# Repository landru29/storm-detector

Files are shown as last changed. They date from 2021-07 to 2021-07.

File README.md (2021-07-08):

# Lightning detector

## Libraries

- OneWire
- SparkFun AS3935
- Adafruit SSD1306
- Piezzo (optional)

## Parts

- 1x Oled 128x64
- 1x AS3935
- 1x Arduino nano Atmega 328P
- 1x Rotary encoder
- 2x Capacitor 0.1µF

## Connections

### Screen OLED

- OLED GND <-> Arduino GND
- OLED VDD <-> Arduino 5V
- OLED SCK <-> Arduino A5
- OLED SDA <-> Arduino A4

### AS3935 Detector

- AS3935 VDD  <-> Arduino 5V
- AS3935 GND  <-> Arduino GND
- AS3935 SCL  <-> ARDUINO D13
- AS3935 MOSI <-> ARDUINO D11
- AS3935 MISO <-> ARDUINO D12
- AS3935 CS   <-> ARDUINO D10
- AS3935 SI   <-> Arduino GND (force spi)
- AS3935 IRQ  <-> Arduino D3
- AS3935 EN_V <-> Arduino 5V
- AS3935 A0   <-> Arduino 5V
- AS3935 A1   <-> Arduino 5V

### Rotary Encoder

``` text
    -----------
 A--|         |
    | Rotary  |--S1
 C--|         |
    | Encoder |--S2
 B--|         |
    -----------
```

- Encoder S1 <-> Arduino GND
- Encoder S2 <-> Arduino D4
- Encoder A  <-> Arduino D2
- Encoder B  <-> Arduino D5
- Encoder C  <-> Arduino GND

### Capacitors

- Cap1 + <-> Arduino D2
- Cap1 - <-> Arduino GND
- Cap2 + <-> Arduino D5
- Cap2 - <-> Arduino GND

### Piezzo (optional)

- Piezzo <-> Arduino D7
- Piezzo <-> Arduino GND

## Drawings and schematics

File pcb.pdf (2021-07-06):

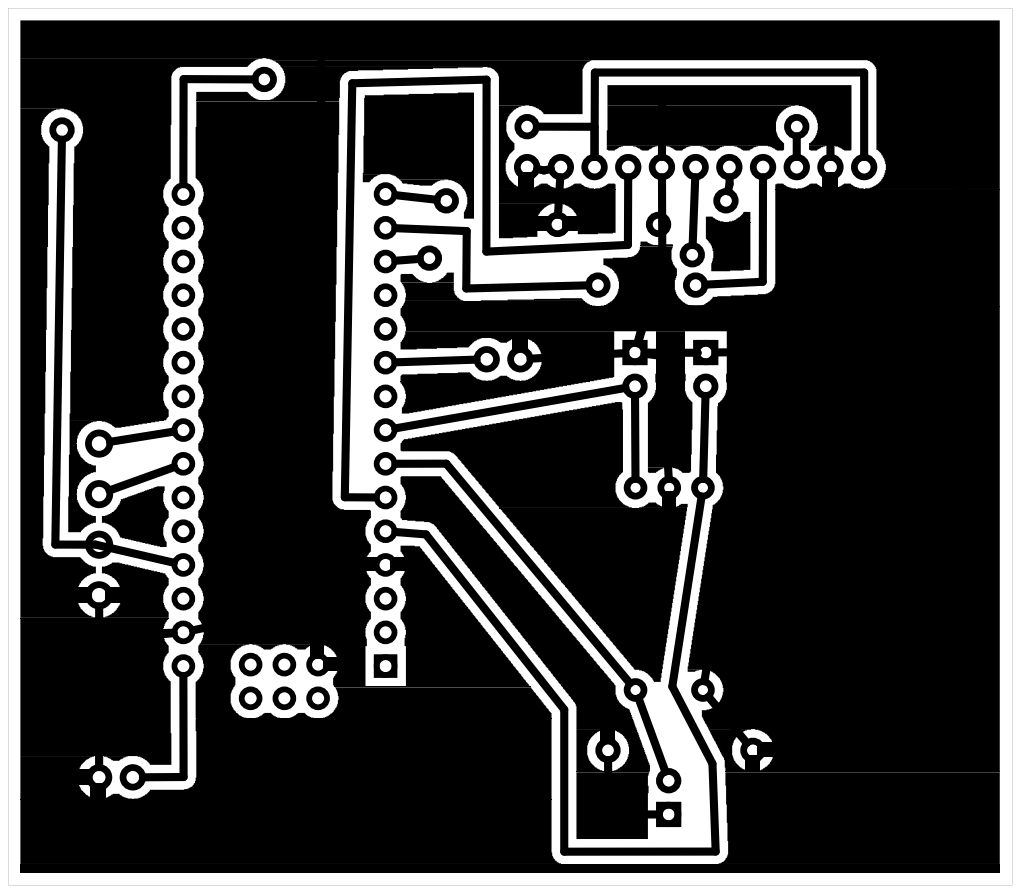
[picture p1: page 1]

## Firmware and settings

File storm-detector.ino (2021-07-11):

#include <Wire.h>
#include <SPI.h>
#include <EEPROM.h>
#include "SparkFun_AS3935.h"
#include "Adafruit_SSD1306.h"
#include "splash.h"

//#define DEBUG

// Button
#define BUTTON 4
#define ROTARY_INTERRUPT 2
#define STEP   5

// Piezzo
#define PIEZZO 7

//SPI chip select pin
#define CHIP_SELECT 10

// Detector mode
#define INDOOR 0x12 
#define OUTDOOR 0xE

// Type of signal
#define LIGHTNING_INT 0x08
#define DISTURBER_INT 0x04
#define NOISE_INT     0x01

#define PAGE_MAIN             1
#define PAGE_MODE             2
#define PAGE_NOISE            3
#define PAGE_WATCHDOG         4
#define PAGE_REJECTIONS       5
#define PAGE_LIGHTNING        6
#define PAGE_MASK_DISTURBERS  7
#define LAST_PAGE             7

// Interrupt pin for lightning detection
#define LIGHTNING_INTERRUPT_PIN 3

// OLED constants
#define SCREEN_WIDTH   128   // OLED display width, in pixels
#define SCREEN_HEIGHT  64    // OLED display height, in pixels
#define OLED_RESET     4     // Reset pin # (or -1 if sharing Arduino reset pin)
#define SCREEN_ADDRESS 0x3C  // See datasheet for Address; 0x3D for 128x64, 0x3C for 128x32

SparkFun_AS3935 lightning;
Adafruit_SSD1306 display(SCREEN_WIDTH, SCREEN_HEIGHT, &Wire, OLED_RESET);

// Counters
unsigned int strikeCount    = 0;
unsigned int noiseCount     = 0;
unsigned int disturberCount = 0;
unsigned int otherCount     = 0;

// Detector configuration
bool modeOut              = true;
bool maskDisturbers       = false;
byte noise                = 2; // Value between 1-7
byte watchDogVal          = 2; // Value between 1-10
byte spike                = 2; // Value between 1-11
byte lightningThresh[4]   = {1, 5, 9, 16}; // Value in [1, 5, 9, 16]
byte lightningThreshIndex = 0;
 

// This variable holds the number representing the lightning or non-lightning
// event issued by the lightning detector.
byte intVal      = 0;
byte distance;
long lightEnergy = 0;

byte page = 1;

bool buttonUp = true;

void setup() {
    loadConfig();
    
    Wire.begin();

    pinMode(BUTTON, INPUT_PULLUP);
    pinMode(ROTARY_INTERRUPT, INPUT_PULLUP);
    pinMode(STEP, INPUT_PULLUP);
    pinMode(PIEZZO, OUTPUT);

    // When lightning is detected the interrupt pin goes HIGH.
    pinMode(LIGHTNING_INTERRUPT_PIN, INPUT);

    #ifdef DEBUG
    Serial.begin(115200);
    #endif // DEBUG

    digitalWrite(PIEZZO, HIGH);

    // SSD1306_SWITCHCAPVCC = generate display voltage from 3.3V internally
    if (!display.begin(SSD1306_SWITCHCAPVCC, SCREEN_ADDRESS)) {
        #ifdef DEBUG
        Serial.println("SSD1306 allocation failed, freezing!");
        #endif // DEBUG
        while (1);
    }

    display.clearDisplay();
    display.drawBitmap(
        (SCREEN_WIDTH - splash_width) / 2,
        (SCREEN_HEIGHT - splash_height) / 2,
        splash_data,
        splash_width,
        splash_height,
        1
    );

    digitalWrite(PIEZZO, LOW);

    // Show initial display buffer contents on the screen --
    // the library initializes this with an Adafruit splash screen.
    display.display();

    delay(2000); // Pause for 2 seconds

    digitalWrite(PIEZZO, HIGH);

    display.setTextSize(1);              // Normal 1:1 pixel scale
    display.setTextColor(SSD1306_WHITE); // Draw white text
    display.cp437(true);                 // Use full 256 char 'Code Page 437' font

    display.writeFillRect(0, 0, SCREEN_WIDTH, 16, 0);
    display.setCursor(0, 0);
    display.println(" LIGHTNINGS - starting ");
    display.display();

    digitalWrite(PIEZZO, LOW);


    #ifdef DEBUG
    Serial.println("AS3935 Franklin Lightning Detector");
    #endif // DEBUG

    SPI.begin(); 

    if (!lightning.beginSPI(CHIP_SELECT)) {
        #ifdef DEBUG
        Serial.println("Lightning Detector did not start up, freezing!");
        #endif // DEBUG
        display.writeFillRect(0, 0, SCREEN_WIDTH, 16, 0);
        display.setCursor(0, 0);
        display.println(" LIGHTNINGS - ERROR ");
        display.writeFillRect(0, 16, SCREEN_WIDTH, SCREEN_HEIGHT-16, 0);
        display.setCursor(0, 16);
        display.println("Detector not found");
        display.display();
        while (1);
    }

    #ifdef DEBUG
    Serial.println("Lightning Detector Ready!");
    #endif // DEBUG
    display.writeFillRect(0, 0, SCREEN_WIDTH, 16, 0);
    display.setCursor(0, 0);
    display.println(" LIGHTNINGS - AS3935 ");
    display.display();

    // The lightning detector defaults to an indoor setting at
    // the cost of less sensitivity, if you plan on using this outdoors
    // uncomment the following line:
    lightning.setIndoorOutdoor(modeOut ? OUTDOOR: INDOOR);

    // Noise floor setting from 1-7, one being the lowest. Default setting is
    // 2. If you need to check the setting, the corresponding function for
    // reading the function follows. 
    lightning.setNoiseLevel(noise);

    // Watchdog threshold setting can be from 1-10, one being the lowest. Default setting is
    // 2. If you need to check the setting, the corresponding function for
    // reading the function follows.    
    lightning.watchdogThreshold(watchDogVal);

    // Spike Rejection setting from 1-11, one being the lowest. Default setting is
    // 2. If you need to check the setting, the corresponding function for
    // reading the function follows.    
    // The shape of the spike is analyzed during the chip's
    // validation routine. You can round this spike at the cost of sensitivity to
    // distant events. 
    lightning.spikeRejection(spike); 

    // This setting will change when the lightning detector issues an interrupt.
    // For example you will only get an interrupt after five lightning strikes
    // instead of one. Default is one, and it takes settings of 1, 5, 9 and 16.   
    // Followed by its corresponding read function. Default is zero. 
    lightning.lightningThreshold(lightningThresh[lightningThreshIndex]); 

    // "Disturbers" are events that are false lightning events. If you find
    // yourself seeing a lot of disturbers you can have the chip not report those
    // events on the interrupt lines. 
    lightning.maskDisturber(maskDisturbers); 

    // When signal is raising on interrupt pin (when a lighting occurs),
    // execute process
    attachInterrupt(digitalPinToInterrupt(LIGHTNING_INTERRUPT_PIN), process, RISING);

    // Manage the rotary encoder
    attachInterrupt(digitalPinToInterrupt(ROTARY_INTERRUPT), rotation, FALLING);

    page = 0;

    #ifdef DEBUG
        int enviVal = lightning.readIndoorOutdoor();
        Serial.print("Are we set for indoor or outdoor: ");  
        if( enviVal == INDOOR ) {
            Serial.println("Indoor.");  
        } else if( enviVal == OUTDOOR ) {
            Serial.println("Outdoor.");  
        } else { 
            Serial.println(enviVal, BIN);
        }
        
        int noiseVal = lightning.readNoiseLevel();
        Serial.print("Noise Level is set at: ");
        Serial.println(noiseVal);

        int watchVal = lightning.readWatchdogThreshold();
        Serial.print("Watchdog Threshold is set to: ");
        Serial.println(watchVal);

        int spikeVal = lightning.readSpikeRejection();
        Serial.print("Spike Rejection is set to: ");
        Serial.println(spikeVal);

        uint8_t lightVal = lightning.readLightningThreshold();
        Serial.print("The number of strikes before interrupt is triggerd: "); 
        Serial.println(lightVal); 

        Serial.print("Are disturbers being masked: ");
        int maskVal = lightning.readMaskDisturber();
        if (maskVal == 1) {
            Serial.println("YES"); 
        } else if (maskVal == 0) {
            Serial.println("NO"); 
        }

    #endif // DEBUG
}

void loop() {
    /*if (digitalRead(LIGHTNING_INTERRUPT_PIN) == HIGH) {
        process();
    }*/

    if ((digitalRead(BUTTON) == HIGH) && buttonUp) {
        buttonUp = false;
        page++;
        if (page>LAST_PAGE) {
            saveConfig();
            page=1;
        }
    }

    if (digitalRead(BUTTON) == LOW) {
        buttonUp = true;
    }

    switch(page) {
    default:
        display.clearDisplay();
        display.setCursor(0, 0);
        display.println("LIGHTNINGS - AS3935 ");
        display.setCursor(0, 16);
        display.print("Strike: ");
        display.println(strikeCount);
        display.setCursor(0, 24);
        display.print("Distance: ");
        display.print(distance);
        display.println("km");
        display.setCursor(0, 32);
        display.print("Energy: ");
        display.println(lightEnergy);

        display.setCursor(0, 48);
        display.print("Noise: ");
        display.println(noiseCount);

        display.setCursor(0, 56);
        display.print("Disturb: ");
        display.println(disturberCount);

        // display.setCursor(0, 56);
        // display.print("Other: ");
        // display.print(otherCount);
        // display.print(" / ");
        // display.print(intVal);
        display.display();
        break;

    case PAGE_MODE:
        display.clearDisplay();
        display.setCursor(0, 0);
        display.println("LIGHTNINGS - MODE ");
        display.setCursor(0, 16);
        display.print("Mode: ");
        if (modeOut) {
            display.println("Outdoor");
        } else {
            display.println("Indoor");
        }
        display.display();
        break;

    case PAGE_NOISE:
        display.clearDisplay();
        display.setCursor(0, 0);
        display.println("LIGHTNINGS - NOISE ");
        display.setCursor(0, 16);
        display.print("Noise: ");
        display.println(noise);
        display.display();
        break;

    case PAGE_WATCHDOG:
        display.clearDisplay();
        display.setCursor(0, 0);
        display.println("LIGHTNINGS - WATCHDOG ");
        display.setCursor(0, 16);
        display.print("Watchdog: ");
        display.println(watchDogVal);
        display.display();
        break;

    case PAGE_REJECTIONS:
        display.clearDisplay();
        display.setCursor(0, 0);
        display.println("LIGHTNINGS - REJECT ");
        display.setCursor(0, 16);
        display.print("Spike reject: ");
        display.println(spike);
        display.display();
        break;

    case PAGE_LIGHTNING:
        display.clearDisplay();
        display.setCursor(0, 0);
        display.println("LIGHTNINGS - THRESHOL ");
        display.setCursor(0, 16);
        display.print("Threshold: ");
        display.println(lightningThresh[lightningThreshIndex]);
        display.display();
        break;
    
    case PAGE_MASK_DISTURBERS:
        display.clearDisplay();
        display.setCursor(0, 0);
        display.println("LIGHTNINGS - MASK ");
        display.setCursor(0, 16);
        display.print("Mask disturb: ");
        if (maskDisturbers) {
            display.println("Yes");
        } else {
            display.println("No");
        }
        display.display();
        break;
    }

    delay(100);
}

void rotation() {
    noInterrupts();
    bool dir = (digitalRead(STEP) == LOW);

    switch(page) {
    case PAGE_MODE:
        modeOut = !modeOut;
        lightning.setIndoorOutdoor(modeOut ? OUTDOOR: INDOOR);
        break;

    case PAGE_NOISE:
        if (dir) {
            noise++;
            if (noise>7) {
                noise=1;
            }
        } else {
            noise--;
            if (noise<1) {
                noise = 7;
            }
        }
        lightning.setNoiseLevel(noise);
        break;

    case PAGE_WATCHDOG:
        if (dir) {
            watchDogVal++;
            if (watchDogVal>10) {
                watchDogVal = 1;
            }
        } else {
            watchDogVal--;
            if (watchDogVal<1) {
                watchDogVal = 10;
            }
        }
        lightning.watchdogThreshold(watchDogVal);
        break;

    case PAGE_REJECTIONS:
        if (dir) {
            spike++;
            if (spike>11) {
                spike = 1;
            }
        } else {
            spike--;
            if (spike<1) {
                spike = 11;
            }
        }
        lightning.spikeRejection(spike);
        break;

    case PAGE_LIGHTNING:
        if (dir) {
            lightningThreshIndex++;
            if (lightningThreshIndex>3) {
                lightningThreshIndex = 0;
            }
        } else {
            if (lightningThreshIndex==0) {
                lightningThreshIndex = 3;
            } else {
                lightningThreshIndex--;
            }
        }
        lightning.lightningThreshold(lightningThresh[lightningThreshIndex]); 
        break;

    case PAGE_MASK_DISTURBERS:
        maskDisturbers = !maskDisturbers;
        lightning.maskDisturber(maskDisturbers); 
        break;
    }
    delay(100);
    interrupts();
}

void process() {
    intVal = lightning.readInterruptReg();
    noInterrupts();
    for(int i=0; i<1; i++) {
        digitalWrite(PIEZZO, HIGH);
        delay(2);
        digitalWrite(PIEZZO, LOW);
    }
    // Hardware has alerted us to an event, now we read the interrupt register
    // to see exactly what it is.
    switch (intVal) {
    case NOISE_INT:
        #ifdef DEBUG
        Serial.println("Noise.");
        #endif // DEBUG
        // Too much noise? Uncomment the code below, a higher number means better
        // noise rejection.
        // lightning.setNoiseLevel(setNoiseLevel);
        noiseCount++;
        break;
    case DISTURBER_INT:
        #ifdef DEBUG
        Serial.println("Disturber.");
        #endif // DEBUG
        // Too many disturbers? Uncomment the code below, a higher number means better
        // disturber rejection.
        // lightning.watchdogThreshold(threshVal);
        disturberCount++;
        break;  
    case LIGHTNING_INT:
        // Lightning! Now how far away is it? Distance estimation takes into
        // account any previously seen events in the last 15 seconds.
        distance = lightning.distanceToStorm();
        lightEnergy = lightning.lightningEnergy();
        #ifdef DEBUG
        Serial.println("Lightning Strike Detected!");
        Serial.print("Approximately: ");
        Serial.print(distance);
        Serial.println("km away!");
        #endif // DEBUG
        strikeCount++;
        break;
    default:
        otherCount++;
        break;
    }
    interrupts();
}

void saveConfig() {
    EEPROM.write(0x00, modeOut ? 1:0);
    EEPROM.write(0x01, noise);
    EEPROM.write(0x02, watchDogVal);
    EEPROM.write(0x03, spike);
    EEPROM.write(0x04, lightningThreshIndex);
    EEPROM.write(0x05, maskDisturbers ? 1:0);
}

void loadConfig() {
    modeOut = (EEPROM.read(0x00)==1);

    noise = EEPROM.read(0x01);
    if ((noise<1) || (noise>7)) {
        noise = 2;
    }

    watchDogVal = EEPROM.read(0x02);
    if ((watchDogVal<1) || (watchDogVal>10)) {
        watchDogVal = 2;
    }

    spike = EEPROM.read(0x03);
    if ((spike<1) || (spike>11)) {
        spike = 2;
    }

    lightningThreshIndex = EEPROM.read(0x04);
    if (lightningThreshIndex>3) {
        lightningThreshIndex = 0;
    }

    maskDisturbers = (EEPROM.read(0x05)==1);
}
